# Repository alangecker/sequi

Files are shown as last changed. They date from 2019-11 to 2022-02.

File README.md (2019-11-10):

# sequi
_a arduino based solar tracker_

board

## BOM

|Count|Product|
|----|---|
|1|**Arduino Nano**|
|1|**DS3231 Module**
|1|**Mini Step Down 12-24V -> 5V 3A**
|4|**Relay 5V SRD-C**
|1|ULN2803A Darlington Driver|
|1|LM4040DBZ-4.1 Voltage Reference|
|3|1μF Capacitor 0805|
|1|0.1μF Capacitor 0805|
|3|100Ω Resistor 0805|
|1|1kΩ Resistor 0805|
|1|10kΩ Resistor 0805|
|1|SMAJ5.0A Diode|
|1|SMAJ24A Diode|
|1|1A Fuse 1206|
|1|5A Fuse ATO|
|3|_5.08mm 2pin terminal plug (optional)_|
|3|_3.5mm 3pin terminal plug (optional)_|
|1|_3.5mm 2pin terminal plug (optional)_|

## License
Copyright (C) 2019 Andreas Langecker

This program is free software: you can redistribute it and/or modify
it under the terms of the GNU General Public License as published by
the Free Software Foundation, either version 3 of the License, or
(at your option) any later version.

This program is distributed in the hope that it will be useful,
but WITHOUT ANY WARRANTY; without even the implied warranty of
MERCHANTABILITY or FITNESS FOR A PARTICULAR PURPOSE.  See the
GNU General Public License for more details.

You should have received a copy of the GNU General Public License
along with this program.  If not, see <http://www.gnu.org/licenses/>.

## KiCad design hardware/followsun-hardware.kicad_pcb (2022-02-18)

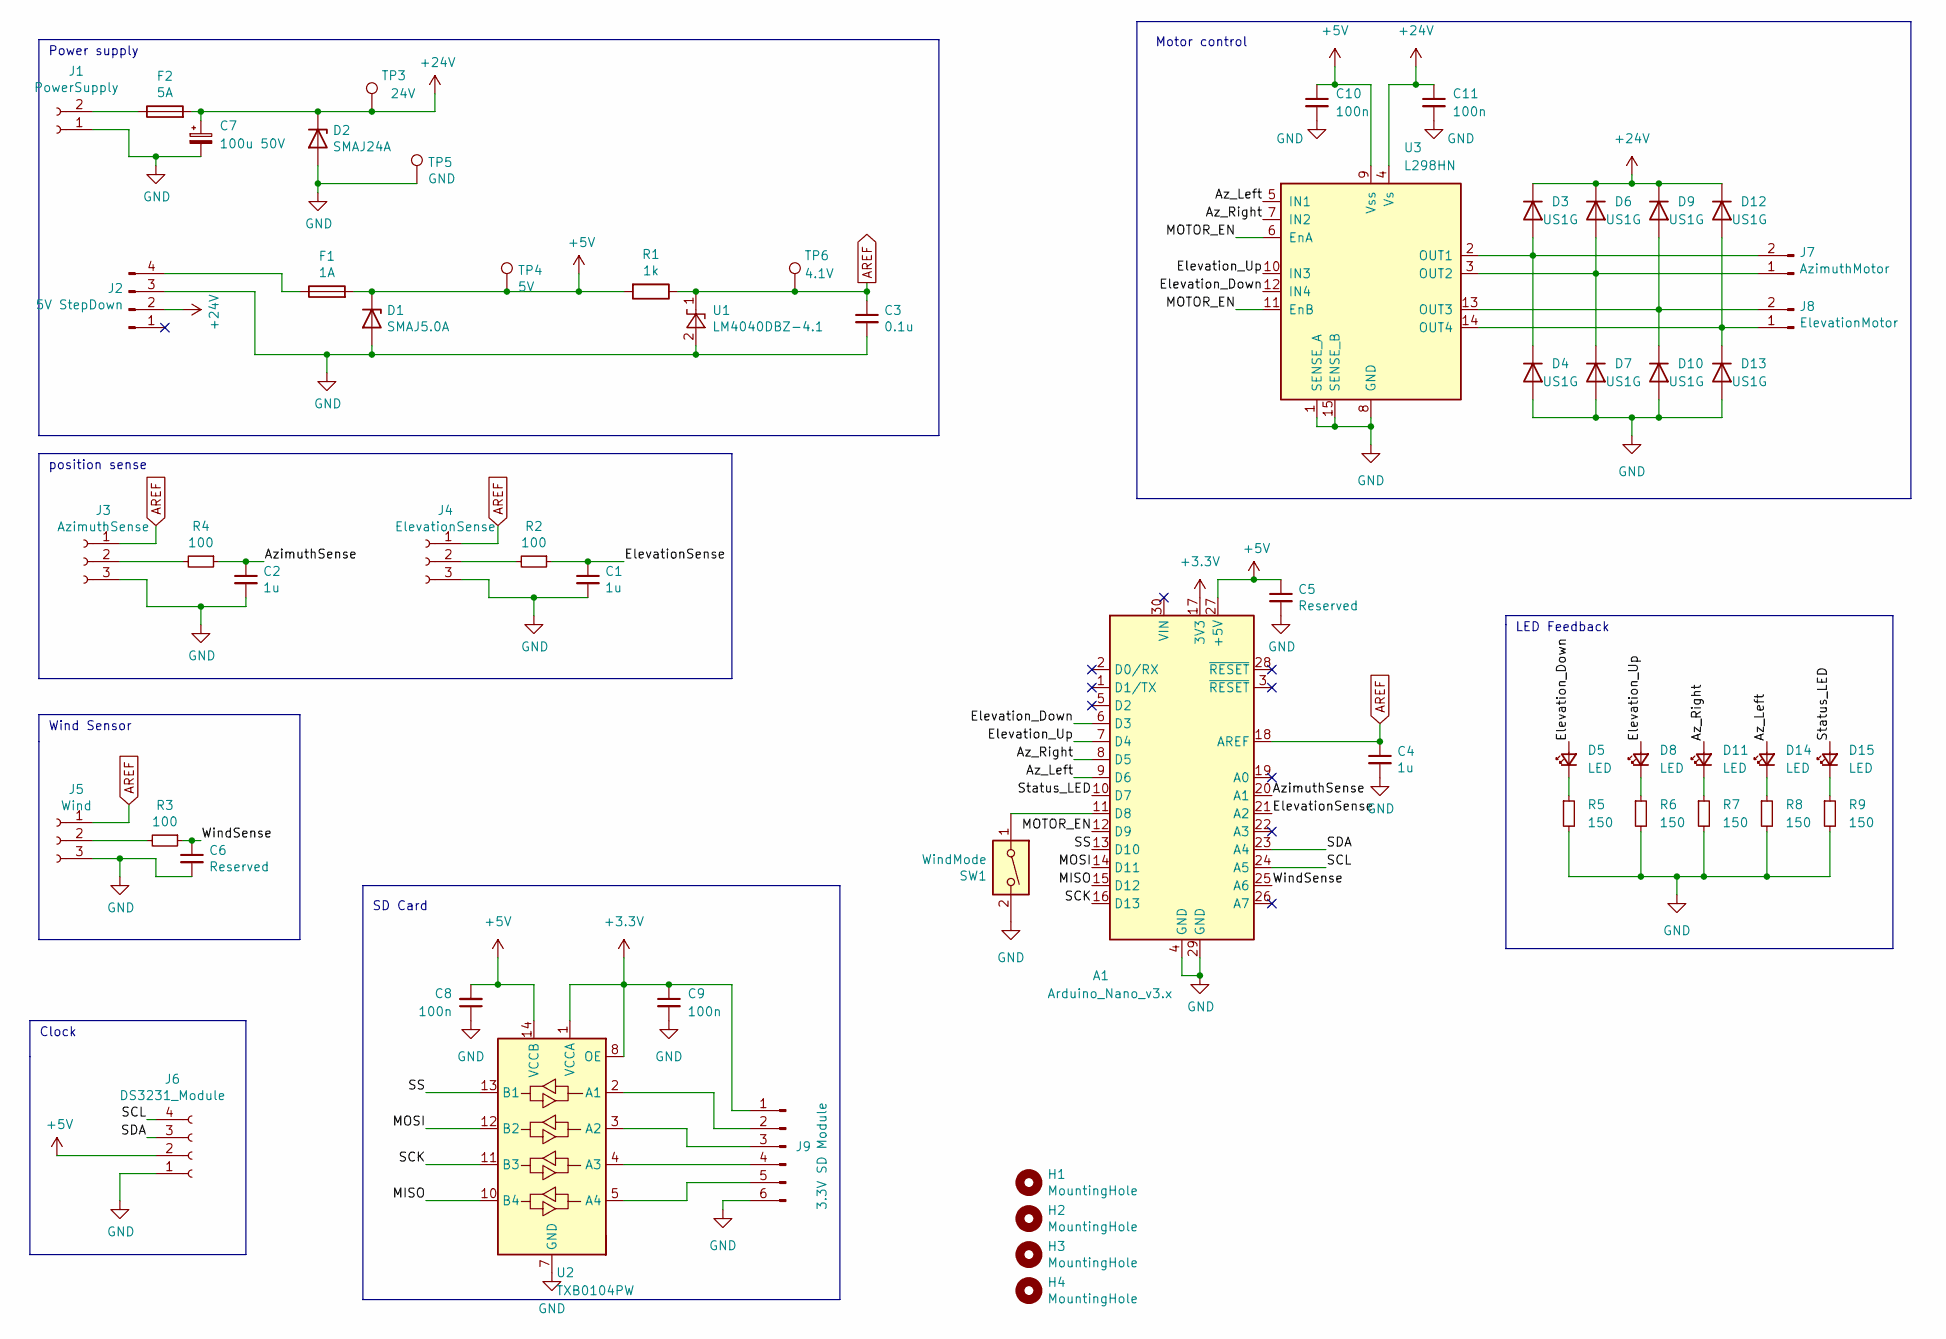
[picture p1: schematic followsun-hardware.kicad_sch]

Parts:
A1: Arduino_Nano_v3.x; Arduino_Nano
C1, C2, C4: 1u; C_0805_2012Metric_Pad1.18x1.45mm_HandSolder
C3: 0.1u; C_0805_2012Metric_Pad1.18x1.45mm_HandSolder
C5, C6: Reserved; C_0805_2012Metric_Pad1.18x1.45mm_HandSolder
C7: 100u 50V; CP_Radial_D8.0mm_P3.50mm
C8, C9, C10, C11: 100n; C_0805_2012Metric_Pad1.18x1.45mm_HandSolder
D1: SMAJ5.0A; D_SMA_Handsoldering
D2: SMAJ24A; D_SMA_Handsoldering
D3, D4, D6, D7, D9, D10, D12, D13: US1G; D_SMA
D5, D8, D11, D14, D15: LED; LED_1206_3216Metric_Pad1.42x1.75mm_HandSolder
F1: 1A; Fuse_1206_3216Metric_Pad1.42x1.75mm_HandSolder
F2: 5A; Fuse_Blade_ATO_directSolder
H1, H2, H3, H4: MountingHole; MountingHole_3mm_Pad_Via
J1: PowerSupply; TerminalBlock_bornier-2_P5.08mm
J2: 5V StepDown; MiniStepDown
J3: AzimuthSense; TerminalBlock_4Ucon_1x03_P3.50mm_Horizontal
J4: ElevationSense; TerminalBlock_4Ucon_1x03_P3.50mm_Horizontal
J5: Wind; TerminalBlock_4Ucon_1x03_P3.50mm_Horizontal
J6: DS3231_Module
J7: AzimuthMotor; TerminalBlock_bornier-2_P5.08mm
J8: ElevationMotor; TerminalBlock_bornier-2_P5.08mm
J9: 3.3V SD Module; PinHeader_1x06_P2.54mm_Vertical
R1: 1k; R_0805_2012Metric_Pad1.20x1.40mm_HandSolder
R2, R3, R4: 100; R_0805_2012Metric_Pad1.20x1.40mm_HandSolder
R5, R6, R7, R8, R9: 150; R_0805_2012Metric_Pad1.20x1.40mm_HandSolder
SW1: WindMode; TerminalBlock_4Ucon_1x02_P3.50mm_Horizontal
TP3: 24V; TestPoint_THTPad_D2.0mm_Drill1.0mm
TP4: 5V; TestPoint_THTPad_D2.0mm_Drill1.0mm
TP5: GND; TestPoint_THTPad_D2.0mm_Drill1.0mm
TP6: 4.1V; TestPoint_THTPad_D2.0mm_Drill1.0mm
U1: LM4040DBZ-4.1; SOT-23
U2: TXB0104PW; TSSOP-14_4.4x5mm_P0.65mm
U3: L298HN; TO-220-15_P2.54x2.54mm_StaggerOdd_Lead4.58mm_Vertical

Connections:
+3V3: A1.17 (3V3), C9.1, J9.1, U2.1 (VCCA), U2.8 (OE)
+5V: A1.27 (+5V), C5.1, C8.2, C10.1, D1.1 (K), F1.2, J6.2, R1.2, TP4.1, U2.14 (VCCB), U3.9 (Vss)
+24V: C7.1, C11.1, D2.1 (K), D3.1 (K), D6.1 (K), D9.1 (K), D12.1 (K), F2.2, J2.2, TP3.1, U3.4 (Vs)
/Az_Left: A1.9 (D6), D14.2 (A), U3.5 (IN1)
/Az_Right: A1.8 (D5), D11.2 (A), U3.7 (IN2)
/AzimuthSense: A1.20 (A1), C2.1, R4.1
/ElevationSense: A1.21 (A2), C1.1, R2.1
/Elevation_Down: A1.6 (D3), D5.2 (A), U3.12 (IN4)
/Elevation_Up: A1.7 (D4), D8.2 (A), U3.10 (IN3)
/MISO: A1.15 (D12), U2.10 (B4)
/MOSI: A1.14 (D11), U2.12 (B2)
/MOTOR_EN: A1.12 (D9), U3.6 (EnA), U3.11 (EnB)
/SCK: A1.16 (D13), U2.11 (B3)
/SCL: A1.24 (A5), J6.4
/SDA: A1.23 (A4), J6.3
/SS: A1.13 (D10), U2.13 (B1)
/Status_LED: A1.10 (D7), D15.2 (A)
/WindSense: A1.25 (A6), C6.1, R3.1
AREF: A1.18 (AREF), C3.1, C4.1, J3.1, J4.1, J5.1, R1.1, TP6.1, U1.1 (K)
GND: A1.4 (GND), A1.29 (GND), C1.2, C2.2, C3.2, C4.2, C5.2, C6.2, C7.2, C8.1, C9.2, C10.2, C11.2, D1.2 (A), D2.2 (A), D4.2 (A), D7.2 (A), D10.2 (A), D13.2 (A), J1.1, J2.3, J3.3, J4.3, J5.3, J6.1, J9.6, R5.2, R6.2, R7.2, R8.2, R9.2, SW1.2, TP5.1, U1.2 (A), U2.7 (GND), U3.1 (SENSE_A), U3.8 (GND), U3.15 (SENSE_B)
unnamed: A1.11 (D8), SW1.1
unnamed: D3.2 (A), D4.1 (K), J7.2, U3.2 (OUT1)
unnamed: D5.1 (K), R5.1
unnamed: D6.2 (A), D7.1 (K), J7.1, U3.3 (OUT2)
unnamed: D8.1 (K), R6.1
unnamed: D9.2 (A), D10.1 (K), J8.2, U3.13 (OUT3)
unnamed: D11.1 (K), R7.1
unnamed: D12.2 (A), D13.1 (K), J8.1, U3.14 (OUT4)
unnamed: D14.1 (K), R8.1
unnamed: D15.1 (K), R9.1
unnamed: F1.1, J2.4
unnamed: F2.1, J1.2
unnamed: J3.2, R4.2
unnamed: J4.2, R2.2
unnamed: J5.2, R3.2
unnamed: J9.2, U2.2 (A1)
unnamed: J9.3, U2.3 (A2)
unnamed: J9.4, U2.4 (A3)
unnamed: J9.5, U2.5 (A4)

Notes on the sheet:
LED Feedback
Wind Sensor
Motor control
Power supply
position sense
SD Card
Clock

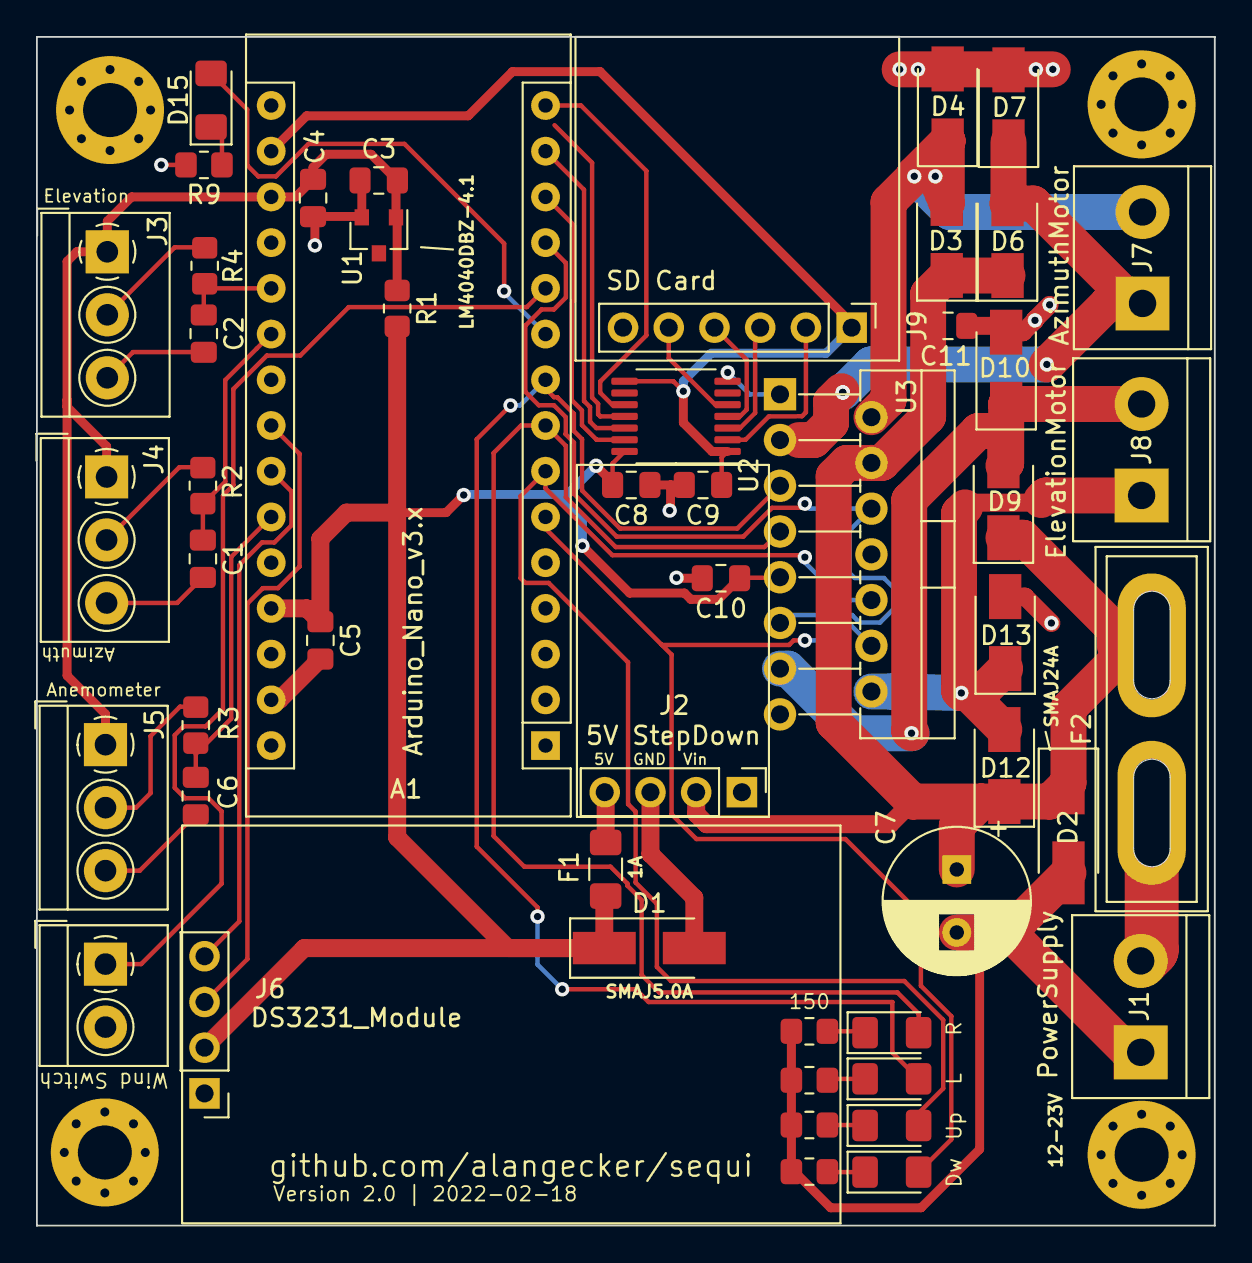
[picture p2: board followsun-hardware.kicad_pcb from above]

Board: 2 copper layers, 65.4 x 66.0 mm, 55 parts (0 on the bottom side), 39 nets.

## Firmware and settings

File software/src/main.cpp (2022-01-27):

#include <Arduino.h>
#include "date.h"
#include "helpers.h"
#include "sensor.h"
#include "motor.h"
#include "consts.h"
#include <RtcDS3231.h>



Coordinates plantLocation = {PLANT_LOCATION_LAT, PLANT_LOCATION_LNG};
Position plantPosition = {0, 0, 0, 0};
Position morningPosition = {0, 0, 0, 0};
Position stormPosition = {0, 0, 0, 0};
Position sunPosition = {0, 0, 0, 0};
int activeMode = MODE_NORMAL;

void setup() {
  Serial.begin(9600);
  date_setup();
  sensor_setup(0x4A);
  motor_setup();
  pinMode(PIN_STORM_SWITCH, INPUT);
  stormPosition.azimuth = STORM_AZIMUTH;
  stormPosition.elevation = STORM_ELEVATION;

  // todo: calculate morning position
  morningPosition.azimuth = 110; 
  morningPosition.elevation = ELEVATION_MIN;
}


void handleCommand(char cmd) {
      switch(cmd) {
        case 'z':
          while(true) {
            if(!Serial.available()) continue;
            uint32_t time = Serial.parseInt();
            Serial.println(time);
            date_update(time);
            return;
          }
          break;
#ifdef AZIMUTH_ENABLE
        case 'a':
          if(get_azimuth_movement() != DIRECTION_LEFT) {
            elevation_stop();
            azimuth_start(DIRECTION_LEFT);
          }
          break;
        case 'd':
          if(get_azimuth_movement() != DIRECTION_RIGHT) {
            elevation_stop();
            azimuth_start(DIRECTION_RIGHT);
          }
          break;
#endif
#ifdef ELEVATION_ENABLE
        case 'w':
          if(get_elevation_movement() != DIRECTION_UP) {
            azimuth_stop();
            elevation_start(DIRECTION_UP);
          }
          break;
        case 's':
          if(get_elevation_movement() != DIRECTION_DOWN) {
            azimuth_stop();
            elevation_start(DIRECTION_DOWN);
          }
          break;
#endif
      }
}


char rx_byte;
unsigned long lastManualCommand = __LONG_MAX__;
boolean inManualMode;
RtcDateTime now;
unsigned long loopCount = 0;

void loop() {
  now = getDate();

  sunPosition = getSunPostion(plantLocation, now);
  plantPosition = get_plant_postion();
  inManualMode = (lastManualCommand + 5l*60l*1000l) >= millis() && !(lastManualCommand > millis());
  // inManualMode = true;
  // print data sometimes
  if(loopCount++ % 10 == 0) {
    print_data(activeMode, now, sunPosition, plantPosition);
  }

  // check limits

#ifdef AZIMUTH_ENABLED
  if(!inManualMode && get_azimuth_movement() == DIRECTION_RIGHT && plantPosition.azimuth >= AZIMUTH_MAX) azimuth_stop();
  if(!inManualMode && get_azimuth_movement() == DIRECTION_LEFT && plantPosition.azimuth <= AZIMUTH_MIN) azimuth_stop();
#endif

#ifdef ELEVATION_ENABLED
  if(!inManualMode && get_elevation_movement() == DIRECTION_UP && plantPosition.elevation >= ELEVATION_MAX) elevation_stop();
  if(!inManualMode && get_elevation_movement() == DIRECTION_DOWN && plantPosition.elevation <= ELEVATION_MIN) elevation_stop();
#endif

  // already in manual mode?
  if(inManualMode) {
    activeMode = MODE_MANUAL;
    if (Serial.available() > 0) {
      rx_byte = Serial.read();       // get the character
      while(Serial.available() > 0) Serial.read(); // flush
      handleCommand(rx_byte);
      lastManualCommand = millis();
    }
    if(lastManualCommand + 600 < millis() && !(lastManualCommand > millis())) {
#ifdef AZIMUTH_ENABLED
      azimuth_stop();
#endif
#ifdef ELEVATION_ENABLED
      elevation_stop();
#endif
    }

  // got new command? switch to manual mode
  } else if (Serial.available() > 0) {
  
    lastManualCommand = millis();
    if(Serial.available() > 1) while(Serial.available() > 0) Serial.read(); // flush

  // normal loop
  } else {
    Position target;



    // is a storm blowing? 
    if(analogRead(PIN_STORM_SWITCH) > 512) {
      activeMode = MODE_STORM;
      target = stormPosition;

    // is sun already down?
    } else if(sunPosition.elevation < -10) {

      //after midnight? go to morning position
      if(now.Hour() < 12) {
        activeMode = MODE_MORNING;
        target = morningPosition;
      } else {
        activeMode = MODE_NIGHT;
        target = plantPosition; // = do nothing
      }
    } else {
      activeMode = MODE_NORMAL;
      target = sunPosition;
    }

#ifdef ELEVATION_ENABLED
    if(!get_azimuth_movement()) {
      if(plantPosition.elevation < target.elevation && get_elevation_movement() != DIRECTION_DOWN) {
        if(target.elevation-plantPosition.elevation > ELEVATION_TOLERANCE && target.elevation <= ELEVATION_MAX) {
          elevation_start(DIRECTION_UP);
        }
      } else if(plantPosition.elevation > target.elevation  && get_elevation_movement() != DIRECTION_UP) {
        if(plantPosition.elevation-target.elevation > ELEVATION_TOLERANCE && target.elevation >= ELEVATION_MIN) {
          elevation_start(DIRECTION_DOWN);
        }
      } else {
        elevation_stop();
      }
    }
#endif

#ifdef AZIMUTH_ENABLED
    if(!get_elevation_movement()) {
      if(plantPosition.azimuth < target.azimuth && get_azimuth_movement() != DIRECTION_LEFT) {
        if(target.azimuth-plantPosition.azimuth > AZIMUTH_TOLERANCE && target.azimuth <= AZIMUTH_MAX) {
          azimuth_start(DIRECTION_RIGHT);
        }
      } else if(plantPosition.azimuth > target.azimuth  && get_azimuth_movement() != DIRECTION_RIGHT) {
        if(plantPosition.azimuth-target.azimuth > AZIMUTH_TOLERANCE && target.azimuth >= AZIMUTH_MIN) {
          azimuth_start(DIRECTION_LEFT);
        }
      } else {
        azimuth_stop();
      }
    } 
#endif

    delay(100);
    loopCount = 10;
  }
}

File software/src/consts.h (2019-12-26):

#ifndef CONSTS_H
#define CONSTS_H

#define PLANT_LOCATION_LAT 48.956
#define PLANT_LOCATION_LNG 11.629

#define AZIMUTH_ENABLED
#define ELEVATION_ENABLED

// sensors
#define AZIMUTH_SCALE 0.47125815
#define AZIMUTH_OFFSET -32

#define ELEVATION_SCALE 0.06481311055
#define ELEVATION_OFFSET 4.85

// limits
#define AZIMUTH_MIN 50
#define AZIMUTH_MAX 300
#define AZIMUTH_TOLERANCE 2

#define ELEVATION_MIN 15
#define ELEVATION_MAX 65
#define ELEVATION_TOLERANCE 1

// storm position
#define STORM_AZIMUTH 180
#define STORM_ELEVATION ELEVATION_MAX

#define TIMEZONE_OFFSET 1

// pin configuration
#define PIN_AZIMUTH_SENSOR A2
#define PIN_ELEVATION_SENSOR A1
#define PIN_STORM_SWITCH A7
#define PIN_ELEVATION_UP 3
#define PIN_ELEVATION_DOWN 4
#define PIN_AZIMUTH_RIGHT 6
#define PIN_AZIMUTH_LEFT 5

#define SOFTWAREI2C_ENABLE 1
#define SOFTWAREI2C_SDA  A3
#define SOFTWAREI2C_SCL  A4


// 
#define DIRECTION_LEFT 1
#define DIRECTION_RIGHT 2
#define DIRECTION_UP 1
#define DIRECTION_DOWN 2

#define MODE_MANUAL 1
#define MODE_NORMAL 2
#define MODE_NIGHT 3
#define MODE_MORNING 4
#define MODE_STORM 5

#endif

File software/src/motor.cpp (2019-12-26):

#include <Arduino.h>
#include "consts.h"
#include "motor.h"

int azimuth_movement = 0;
int elevation_movement = 0;

#define MOTOR_OFF LOW
#define MOTOR_ON HIGH


void motor_setup() {

#ifdef AZIMUTH_ENABLED
  digitalWrite(PIN_AZIMUTH_RIGHT, MOTOR_OFF);
  digitalWrite(PIN_AZIMUTH_LEFT, MOTOR_OFF);
  pinMode(PIN_AZIMUTH_RIGHT, OUTPUT);
  pinMode(PIN_AZIMUTH_LEFT, OUTPUT);
#endif

#ifdef ELEVATION_ENABLED
  digitalWrite(PIN_ELEVATION_UP, MOTOR_OFF);
  digitalWrite(PIN_ELEVATION_DOWN, MOTOR_OFF);
  pinMode(PIN_ELEVATION_UP, OUTPUT);
  pinMode(PIN_ELEVATION_DOWN, OUTPUT);
#endif

}


int get_azimuth_movement() {
    return azimuth_movement;
}
#ifdef AZIMUTH_ENABLED
void azimuth_start(int direction) {
    if(azimuth_movement == direction) return;
    azimuth_movement = direction;
    if(azimuth_movement == DIRECTION_LEFT) {
        digitalWrite(PIN_AZIMUTH_RIGHT, MOTOR_OFF);
        digitalWrite(PIN_AZIMUTH_LEFT, MOTOR_ON);
    } else {
        digitalWrite(PIN_AZIMUTH_RIGHT, MOTOR_ON);
        digitalWrite(PIN_AZIMUTH_LEFT, MOTOR_OFF);
    }
}
void azimuth_stop() {
    azimuth_movement = 0;
    digitalWrite(PIN_AZIMUTH_RIGHT, MOTOR_OFF);
    digitalWrite(PIN_AZIMUTH_LEFT, MOTOR_OFF);
}
#endif

int get_elevation_movement() {
    return elevation_movement;
}

#ifdef ELEVATION_ENABLED

void elevation_start(int direction) {
    if(elevation_movement == direction) return;
    elevation_movement = direction;
    if(elevation_movement == DIRECTION_UP) {
        digitalWrite(PIN_ELEVATION_DOWN, MOTOR_OFF);
        digitalWrite(PIN_ELEVATION_UP, MOTOR_ON);
    } else {
        digitalWrite(PIN_ELEVATION_DOWN, MOTOR_ON);
        digitalWrite(PIN_ELEVATION_UP, MOTOR_OFF);
    }
}
void elevation_stop() {
    elevation_movement = 0;
    digitalWrite(PIN_ELEVATION_DOWN, MOTOR_OFF);
    digitalWrite(PIN_ELEVATION_UP, MOTOR_OFF);
}
#endif
